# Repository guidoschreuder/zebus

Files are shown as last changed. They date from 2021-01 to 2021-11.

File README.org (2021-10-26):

#+TITLE:     Zebus
#+AUTHOR:    Guido Schreuder
#+EMAIL:     guido.schreuder@ruimtepuin.be

* Manage the Valliant heater

** Goals
Create system to control the heater

Conceived features:
- room controller:
  - display to represent status
    - requested room temperature
    - room temperature
    - heater flow temp (ebusd message 'FlowTemp', also rounded in `status01`)
    - heater return temp (ebusd message 'ReturnTemp', also rounded in `status01`)
    - outside temperature
    - heater mode: heating/hot water (ebusd message 'HwcDemand' or 'HwcWaterflow')
    - tap water temperature (ebusd message 'FlowTemp' when tap is running)
    - flame on/off (ebusd message 'Flame')
    - pump on/off (ebusd message 'WP')
    - heater modulation
    - power usage (?) to be tested (ebusd message 'PowerValue')
  - sensor for actual room temperature
  - controls to set required temperature
- +communicate date and outside temperature to heater unit+ impossible and irrelevant, see [[* +Broadcast datetime+]]
- control remotely using a telegram bot, that way we do not need to open any ports to the outside
- (LOW PRIO, MAYBE LATER) display graphs over time of relevant values

** Topology (work in progress)
- room controller (ESP32 + display + temp-sensor)
- retrieve outside temp from free API service like OpenWeatherMap +outdoor unit, communicates temperature to "master" ESP32 on heater unit over ESP-NOW+
- (LOW PRIO, MAYBE LATER) master forwards to MQTT for monitoring/graphing

** Challenges
- ✓ eBUS communication protocol (pretty much got this down)
- Valliant's eBUS commands are proprietary
- ESP32 ULP programming is in assembler

* tasks
Tasks should re-ordered so the first items should be the first things to pick up, items that are DONE need to move to [[* project log]]

** TODO determine preferred topology to use  (work in progress)
+consider ESP-NOW so "sensor" modules can profit from reduced "ON" time.+

+This needs a "master" though to forward to MQTT if required.+

+Good read and entry point is here: https://hackaday.io/project/174898-esp-now-weather-station+

New idea on topology is to use a single ESP32 as thermostat which harvests energy from eBUS for power.

The advantage is that there is no wireless communication needed for basic thermostat functionality.

This does however require a more sophisticated power design as we need a LiPo battery (or similar) with circuitry and most likely use of ESP32 ULP to stay within the power budget.

Wireless connectivity is still possible for things like getting NTP, outside temperature from a free API service and communicating as a telegram bot, but display and wireless need to repect the available energy budget.
** TODO prototype switching display on and off with mosfet
When operating in power-harvest mode we do not want the display on when maintenance chores are done.

The display does not have a pin to regulate the backlight, so it needs to be switched off completely when in sleep mode.
** TODO integrate a rotary encoder and buttons (capacitive?) for controlling the controller
** TODO integrate room temperature sensor
** TODO [#B] prototype power harvesting
Starting point are project that use solar energy like here https://randomnerdtutorials.com/power-esp32-esp8266-solar-panels-battery-level-monitoring/

This will include staring to use ESP32 ULP programming in assembler to measure the voltage/battery level in low power mode
** TODO [#C] create PCB with all components integrated
All basic functionality needs to be prototyped and tested before doing this.

Consider using JLCPCB assembly, this way we can use SMD without the hassle of sourcing SMD components, let alone soldering them
** TODO [#C] create case for thermostat unit

* documentation
** calculating power usage

#+NAME: ebusd raw log for getting data
#+BEGIN_SRC sh
2021-10-26 07:24:00.949 [update notice] sent read bai PartloadHcKW QQ=31: 20
2021-10-26 07:24:00.951 [bus notice] >3108b509030d0704ee<0001148f>00
2021-10-26 07:27:48.647 [update notice] sent read bai ModulationTempDesired QQ=31: 35.0
2021-10-26 07:27:48.650 [bus notice] >3108b509030d2e000c<00025e01a2>00
#+END_SRC

#+NAME: calculate current power for heating
#+BEGIN_SRC C
CurrentPower = PartloadHcKW * ModulationTempDesired / 100%

CurrentPower = 20 * 35.0 /100 = 7KW
#+END_SRC

discussion on calculating power consumption: https://github.com/john30/ebusd-configuration/issues/89

** code coverage
After running tests, code coverage report can be generated by executing the following commands:

#+NAME: code coverage generation
#+BEGIN_SRC sh
$ lcov --capture --directory .pio/build --output-file coverage.info
$ genhtml coverage.info --output-directory out
#+END_SRC

** display

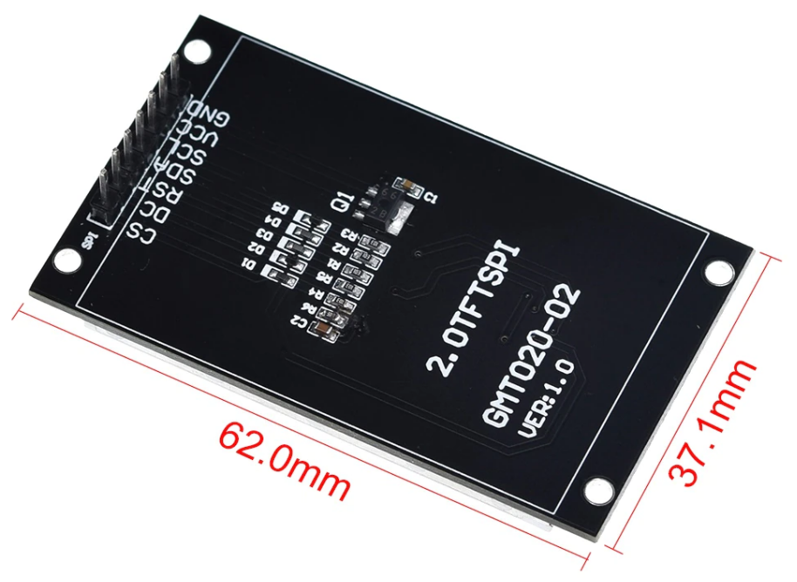
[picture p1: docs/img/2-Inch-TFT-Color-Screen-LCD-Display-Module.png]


driver IC: ST7789VW

size: 240x320 px

library used: TFT\under{}eSPI

bought here: https://www.aliexpress.com/item/4000830895622.html

| pinout | meaning          | ESP32   | note       |
|--------+------------------+---------+------------|
| CS     | chip select      | GND     | active low |
| DC     | SPI Data Command | GPIO 27 |            |
| RST    | Reset            | GPIO 5  |            |
| SDA    | SPI MOSI         | GPIO 23 |            |
| SCL    | SPI clock        | GPIO 18 |            |
| VCC    |                  | +3.3    |            |
| GND    |                  | GND     |            |

** random assortment of links
 - http://www.pittnerovi.com/jiri/hobby/electronics/ebus/index.html
 - https://github.com/slavikb/BaiMon/blob/master/BaiMon.ino
 - https://www.14core.com/wiring-and-flashing-programming-esp-32-esp32s-with-usb-ttl-uart/
 - https://www.thingforward.io/techblog/2017-08-08-embedded-testing-with-platformio-part-2.html
 - set datetime: https://github.com/john30/ebusd/issues/286
 - formatting C time struct: https://www.ibm.com/docs/en/i/7.3?topic=functions-strftime-convert-datetime-string

* project log
** DONE create hardware interface for eBUS
    CLOSED: [2021-01-17 Sun 01:48]
** DONE get hardware interface to work with ebusd and experiment a bit
    CLOSED: [2021-01-17 Sun 01:48]
** DONE build bus power supply so testing can be done in stand-alone mode
    CLOSED: [2021-01-17 Sun 01:50]
** DONE experiment with programming new ESP32 boards
    CLOSED: [2021-01-18 Mon 03:19]
that was easy as pie :)
** DONE get ESP32 to listen in on eBUS messages and forward them ad-verbum to serial port for monitoring/debugging
    CLOSED: [2021-01-24 Sun 05:14]
** DONE implement queues for actions "to be done" and "messages completed"
   CLOSED: [2021-08-30 Mon 00:29]
status:

implemented a pretty simple queue

later i found out about the provided facilities of FreeRTOS (live and learn...)

the simple mock queue is however still very usefull for unit-testing in native mode

actual implementation will use FreeRTOS queues provided by ESP-IDF/FreeRTOS
** DONE learn how to use FreeRTOS queues
     CLOSED: [2021-01-24 Sun 05:13]
** DONE use queues for storing historic message
     CLOSED: [2021-01-24 Sun 05:15]

** DONE reply to "Identification (Service 07h 04h)"
    CLOSED: [2021-01-24 Sun 04:28]

** DONE tackle the arbitration challenge
   CLOSED: [2021-08-30 Mon 00:29]
** DONE get ESP board to interface with 2.0" display
   CLOSED: [2021-08-29 Sun 19:06]
** DONE setup polls for basic data and extract the relevant data from the responses
   CLOSED: [2021-09-04 Sat 00:55]
suggested for this todo are some of the messages already known:
- FlowTemp
- ReturnTemp
- HwcWaterflow
- Flame

As a reward these values can already be put on display, gaining some instant gratification and bragging rights.

** DONE connect to WiFi
   CLOSED: [2021-09-05 Sun 19:55]
** DONE Setup and display time over NTP
   CLOSED: [2021-09-05 Sun 22:01]
** DONE display eBUS connectivity
   CLOSED: [2021-09-06 Mon 01:29]
** DONE figure out what our power budget is
   CLOSED: [2021-09-06 Mon 17:58]
   Shorting 390 Ohm across the eBUS still held an upper voltage of 20.2V and bus seemed to work fine.

   This equals a current draw of ~52mA, or 1.06W, this is actually quite substantial, this was measured with a really tiny copper wire (telephone wire) connection to the heater, so losses will be less on thicker wiring.

   Using 220 Ohm the bus still managed to do some communication but errors did occur, the maximum voltage dropped to 19.2V. This equals a current draw of ~87mA and a power of 1.68W! The resistor got really toasty and discoloured!

   At 336 Ohm (60mA, 1.2W) bus still behaved perfectly.

   In conclusion, round about 50mA or a little more seems to be a very safe limit with only a single device on the bus besides the heater.
** +Broadcast datetime+
+Send broadcast of datetime and check ebusd messages 'DCFState', 'DCFTimeDate', 'DateTime'.+

My line of thinking was completely wrong, i assumed the DCF77 device was "Yet Another eBUS device". It is not. It is a module connected to a separate port on the heater. The broadcasts (presumably) are by the heater when it has detected a DCF signal.

Further more, i have not found any way to set the date/time on the heater through eBUS, and believe me, i've tried.

In the end it is not really relevant anyway, the room controller takes on the full role of director anyway when controlling the heater over eBUS, so the date/time on the heater is then completely irrelevant.
** +send current room temperature to heater+
Irrelevant for the same reason outlined in [[* +Broadcast datetime+]], in eBUS mode the heater is just a rather dumb slave dancing to the tune of puppet master room controller

** DONE setup separerate ESP32 as temperature logger
   CLOSED: [2021-09-14 Tue 08:00]
read sensor and output value to serial port
** DONE setup ESP-NOW and communicate temperature sensor readings to room controller
   CLOSED: [2021-09-14 Tue 19:16]
** DONE switch ESP-NOW polling from master to slave
   CLOSED: [2021-09-20 Mon 03:08]
It makes little sense for the master to loose WiFi connection to send beacons because of channel switching. Instead the slave(s) should do this as they have no active WiFi connection to begin with.
** DONE implement HMAC on ESP-NOW messages
   CLOSED: [2021-09-22 Wed 00:22]
Data sent over ESP-NOW is not sensitive so encryption is not very relevant. However, we do not want rogue data being operated on by the controller.

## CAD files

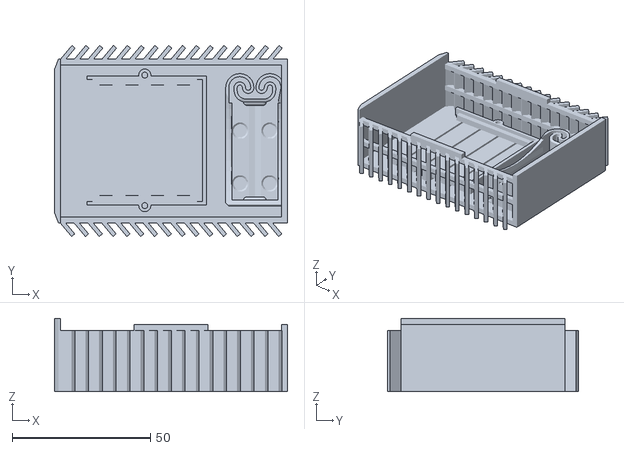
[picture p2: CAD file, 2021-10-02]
3d/outdoor-sensor/outdoor-sensor.stl
84.4 x 69.2 x 26.6

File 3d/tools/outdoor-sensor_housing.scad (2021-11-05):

// Which part would you like to see?
part = "box"; // [box:box only,front:front only]

// Heigth of box in mm (Inside).
height = 75; 

// Width of box in mm (Inside).
width = 52;

// Depth of box in mm (Inside).
depth = 16;

// Wall thicknes of box in mm.
thickness = 1.5; 

// Diameter of screw hole in mm.
diameter_hole = 0;

// Length of the slats in mm.
length_slats = 7;

// Pointed or flat roof?
roof = "flat"; // [pointed:pointed roof, flat:flat roof]

roof_angle = 115;

module housing(){
    cube([height,width+2*thickness,thickness]);
    rotate([0,-90,0])
        translate([0,0,-height-thickness])
            cube([depth+2*thickness,width+2*thickness,thickness]);
    if (roof == "flat") {
        rotate([0,0,90])
            cube([width+2*thickness,thickness,depth+3*thickness]);
    } else {
        rotate([0,0,90])
            cube([width+2*thickness,width,depth+3*thickness]);
    }
    for (a=[-1:5:height-5])
        translate([a,width+thickness+1,0])
            rotate([90,0,50])
                cube([length_slats,depth+thickness,1.5]);
    for (b=[0:5:height-5])
        translate([b,thickness,0])
            rotate([90,0,-50])
                cube([length_slats,depth+thickness,1.5]);
    translate([0,0,depth])
        cube([height,thickness,thickness]);
    translate([0,width+thickness,depth])
        cube([height,thickness,thickness]);
    translate([0,0,depth/2])
        cube([height,thickness,thickness]);
    translate([0,width+thickness,depth/2])
        cube([height,thickness,thickness]);
    translate([height/3,0,depth+thickness])
        cube([height/3,thickness,thickness]);
    translate([height/3,width+thickness,depth+thickness])
        cube([height/3,thickness,thickness]);
}

module cutouthousing(){
    translate([height/5,width/2+thickness,-1])
        cylinder(h=thickness+2, r=diameter_hole/2);

    translate([0,-2,depth+5*thickness])
        rotate([270,0,roof_angle])
            cube([width+thickness,depth+6*thickness,100]);
    translate([0,width+2*thickness+2,-thickness])
        rotate([90,0,-roof_angle])
            cube([width+4*thickness,depth+6*thickness,100]);   
}

module front(){
    cube([height,width+2*thickness,thickness]);    
}

module cutoutfront(){
    translate([height/3,0,0])
        cube([height/3,thickness,thickness]);
    translate([height/3,width+thickness,0])
        cube([height/3,thickness,thickness]);
}
    

$fn=50;

module box(){
    difference(){
        housing();
        cutouthousing();
    }
}

module door(){
    difference(){
        front();
        cutoutfront();
    }
}

print_part();

module print_part() {
	if (part == "box") {
		translate([-height/2-thickness,-width/2-thickness,0]) box();
	} else if (part == "front") {
		translate([-height/2,-width/2,0]) door();
	} 
}

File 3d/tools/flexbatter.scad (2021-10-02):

//////////////////////////////////////////////////////////////////////////////////////
///
///  FLEXBATTER: Flexing battery holder with built-in spring
///
///  This file generates battery holders for arbitrary cylindrical sizes.
///  The number of batteries compartments, the number of batteries in each compartment
///  and the battery size are fully parametrized.
///
///  The usual metallic spring at the minus pole is replaced by a
///  flexible printed spring, which is pressing the contacts firmly to 
///  the battery.
///
///  The contacts for the plus and minus pole can easily be made by
///  a few windings of the uninsulated ends of the connecting wires.
///  Each battery compartment contains are several holes to the outside
///  as well ad to the neighboring compartments, through which connecting
///  wires can be passed for easy configuring of parallel, serial or
///  balanced-serial battery packs.
///  
///  The preconfigured battery sizes are:
///  AA, AAA, C, D, 18650(Li-Ion), 18650P(protected Li-Ion), CR123A(16340)
///  
///  Given that the printed plastic spring needs to be flexible, ABS is the material
///  of choice here.
///
//////////////////////////////////////////////////////////////////////////////////////
///
///  2014-09-09 Heinz Spiess, Switzerland
///  2015-07-25 multi-cell compartments added
///
///  released under Creative Commons - Attribution - Share Alike licence (CC BY-SA)
//////////////////////////////////////////////////////////////////////////////////////

// build a cube with chamfered edges
module chamfered_cube(size,d=1){
   hull(){
     translate([d,d,0])cube(size-2*[d,d,0]);
     translate([0,d,d])cube(size-2*[0,d,d]);
     translate([d,0,d])cube(size-2*[d,0,d]);
   }
}


// draw an arc width height h between radius r1..r2 and angles a1..a2
module arc(r1,r2,h,a1=0,a2=0){
     if(a2-a1<=180){
        difference(){
           cylinder(r=r2,h=h);
           translate([0,0,-1])cylinder(r=r1,h=h+2);
	   rotate(a2)translate([-r1-r2,0,-1])cube([2*(r1+r2),2*(r1+r2),h+2]);
	   rotate(a1+180)translate([-r1-r2,0,-1])cube([2*(r1+r2),2*(r1+r2),h+2]);
        }
     } else {
           difference(){
              cylinder(r=r2,h=h);
              translate([0,0,-1])cylinder(r=r1,h=h+2);
              intersection(){
	       rotate(a2)translate([-r1-r2,0,-1])cube([2*(r1+r2),2*(r1+r2),h+2]);
	       rotate(a1+180)translate([-r1-r2,0,-1])cube([2*(r1+r2),2*(r1+r2),h+2]);
	      }
           }
     }
}

/////////////////////////////////////////////////////////////////////////////////
// sline - generate a "snake line" of width w and height h 
// with a arbitrary sequence of segments defined by a radius and a turning angle
//
//   angle[i] > 0  left turn / counter-clockwise
//   angle[i] < 0  left turn / clockwise
//   angle[i] = 0  straight segment with length radius[i]
//
/////////////////////////////////////////////////////////////////////////////////
// Heinz Spiess, 2014-09-06 (CC BY-SA)
/////////////////////////////////////////////////////////////////////////////////
module sline(angle,radius,i,w,h){
   r=abs(radius[i]);
   a=angle[i];
   scale([angle[i]>=0?1:-1,1,1])
         translate([a?r:0,0,0]){
	    translate([-w/2,-r-0.01,0])cube([w,0.02,h]); // tiny overlap!
            if(a)arc(r-w/2,r+w/2,h,a);
	    else if(r>0)translate([-w/2,-r,0])cube([w,r,h]);
      if(i+1<len(angle))
           rotate(angle[i])
	      translate([a?-r:0,a?0:-r,0])
	         sline(angle,radius,i+1,w,h);
  }
}

ew=0.56;   // extrusion width
eh=0.25;   // extrusion height

//////////////////////////////////////////////////////////////////////////////////
//
//  FLEXBATTER:  Flexing battery holder with integrated plastic spring
//
//////////////////////////////////////////////////////////////////////////////////
module flexbatter(
  n=1,             // number of compartments side by side
  m=1,             // number of cells in one compartment
  l=65,            // length of cell
  d=18,            // diameter of cell
  hf=0.75,         // relative hight of cell (1=full diameter)
  shd=3,           // screw hole diameter
  eps=0.28,        // extra diameter space 
  oh=0,            // overhang to avoid lifting of cell
  el=0,            // extra spring length (needed for small cells)
  xchan=[1/4,3/4], // relative position of traversal wire channels
  deepen=0,        // relative deepening for side grip of batteries 
  df=1,            // relative deepening radius
  lcorr=0,         // length correction for multicell compartments
  $fn=24
  ){

  w = (m>1?6:4)*ew;  // case wall thickness
  wz = 2;            // bottom wall thickness
  ws = 2*ew; // spring wall thickness
  ch = ws; // edge chamfering

  r = d/5+2*ws; // linear spring length (depends on sline() call!)
  L = m*l+lcorr;// corrected overall lenth
  lc = L/m;     // corrected cell length

   for(i=[0:n-1])translate([0,i*(d+2*w-ws),0]){ // generate n battery cases
      difference(){
         
         union(){
            difference(){
               // main body
               translate([0,-w-d/2,0])
	          chamfered_cube([L+w,d+2*w+(i<n-1?ws:0),hf*d+wz+ch],ch);
	       // main cavity
               jmin=deepen>0?0:-1;
	       for(j=[0:m-1])translate([j*lc,0,0])hull(){
                  translate([-0.01,-d/2+(j>jmin?oh:0),wz])cube([lc/4,d-(j>jmin?2*oh:0),d+1]);
                  translate([lc*0.75,-d/2+(j<m-1?oh:0),wz])cube([lc/4+0.01,d-(j<m-1?2*oh:0),d+1]);
               }
	       // cavity for locating plastic spring
               translate([-1,-d/2,-1])cube([2,d,d+wz+2]);
	       // small cylindrical carving of walls and bottom
	       translate([-1,0,d/2+wz])rotate([0,90,0])cylinder(r=d/2+eps,h=L+1);
            }
      
            // plastic spring for minus pole
            for(sy=[-1,1])scale([1,sy,1]) {
               D=d+2*w-2*ws-0.7;
               translate([ch,d/2+w-ws/2,0])rotate(-90)
		  //sline([90,0,120,90,120,90,0],[d/8+2,d/6,d/8-1,d/8,-d/8,d/8,d/2],0,ws,hf*d+w);
		  sline([0,180,0,180,0,-180,0,90,0],[r+ch+el,D/4,el,D/12,el/2,D/12,1+el/2,D/5,D/3],0,ws,hf*d+wz);


            }
         }
      
         // lower and upper holes for contacts
         for(z=[-2*ws,2*ws])
            translate([-2*ws,-w,wz-ws/2+d/2+z])cube([L+2*w+2,2*w,ws]);
      
         // longitudinal bottom wire channel
         translate([-2*ws,0,0])rotate([0,90,0])cylinder(r=wz/2,h=L+w+2+r,$fn=5);
      
         // traversal bottom wire channels
         for(x=L*xchan)translate([x,-d/2-w-1,-eh]) rotate([-90,0,0])cylinder(r=wz/2,h=d+2*w+ws+2,$fn=6);
   
         // grip deepening
	 if(deepen!=0)
	    for (j=[(deepen>0?0:m-1):m-1])
            translate([j*lc+lc/2-0.5,-d/2-w-0.01,wz+d+df*l])
	       rotate([-90,0,0]){
              adeepen=deepen>0?deepen:-deepen;
	          cylinder(r=df*l+adeepen*d,h=d+2*w+2*ws+2,$fn=72);
	          if(i==0)cylinder(r1=df*l+adeepen*d+ch,r2=df*l+adeepen*d,h=ch+0.02,$fn=72);
	          if(i==n-1)translate([0,0,d+2*w-ch])cylinder(r2=df*l+adeepen*d+ch,r1=df*l+adeepen*d,h=ch+0.02,$fn=72);

               }
         // conical screw holes in corners
         for(x=[7+shd,L-2*shd])for(y=[-d/2+shd,d/2-shd])
             translate([x,y,-1]){
                cylinder(r=shd/2,h=wz+2);
                translate([0,0,wz-shd/2+1])cylinder(r1=shd/2,r2=shd,h=shd/2+0.01);
             }

         // holes for wires passing inside
         for(sy=[-1,1])scale([1,sy,1]){
	    translate([L-1,-d/2,wz])cube([w+2,2,2]);
            for(x=[3,L-7])translate([x,-d/2-w-ws-1,wz])cube([3,w+ws+3,2]); 
            translate([3,-d/2+w/2-0.75,-1])cube([3,1.5,wz+2]); 
            translate([-0.5,-d/2+w/2,0])rotate([0,90,0])cylinder(r=w/2,h=6.5,$fn=5);
         }

         // engrave battery symbol
	 for(j=[0:m-1])translate([j*lc,0,0]){
	    translate([w+l/2,d/4+1,wz])cube([l/5,d/4.5,4*eh],true);
	    translate([w+l/2+l/10,d/4+1,wz])cube([d/7,d/10,4*eh],true);
	    // engrave plus symbol
	    sy=(l>12*shd)?1:-1; // for short batteries +- on the side
	       translate([w+l/2+l/(sy>0?5:10),sy*(d/4+1),wz]){
	          cube([1,d/4,4*eh],true);
	          cube([d/4,1,4*eh],true);
               }
	    // engrave minus symbol
	       translate([w+l/2-l/(sy>0?5:10),sy*(d/4+1),wz])
	          cube([1,d/4,4*eh],true);
            
	 }
   
         //correction for middle separators
         //if(i<n-1) translate([-d,d/2+w-ws/2,-1])cube([d,ws/2+0.1,d+2]);
	 //else translate([1,d/2+w,-0.01])cylinder(r1=ch,r2=0,h=ch);
         //if(i>0) translate([-d,-d/2-w-0.1,-1])cube([d,ws/2+0.1,d+2]);
	 //else translate([1,-d/2-w,-0.01])cylinder(r1=ch,r2=0,h=ch);


      }


      // horizontal contact bulges (+ and - pole)
      for(x=[-0.3,L])
         hull()for(y=[-3+el,3-el])
            translate([x,y,wz+d/2])sphere(r=ws);
   
      // vertical contact bulge (+ pole only)
      if(0)hull()for(z=[-3+el,3-el])for(x=[0,w-ws])
            translate([L+x,0,wz+d/2+z])sphere(r=ws);



   }

}
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

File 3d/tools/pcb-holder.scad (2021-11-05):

// Width of the PCB
pcb_width = 50.1;

// Length of the PCB
pcb_length = 50.1;

// PCB thickness
pcb_thickness = 1.6;

// Height from top of baseplate to bottom of PCB
pcb_heigth_offset = 3.5;

// Thickness of base plate
baseplate_thickness = 1.5;

// Thickness of the ledge that supports the PCB
pcb_support_width = 2.1;

pcb_support_clear_corner = 2.1;

// Thickness of the ridge that keeps the PCB
ridge_width = 3.7;

// number of slats cut out of baseplate
num_slats = 6;

sides = "none"; // ["none", "front", "back", "both"]

// number of PCB retainment screws per side
num_pcb_retainment_screws_per_side = 1;

// diameter of the PCB retainment screw hole
pcb_retainment_screws_hole_diameter = 3.2;

print_part();

num_sides = (sides == "both") ? 2 : ((sides == "front" || sides == "back") ? 1 : 0);
total_width = pcb_width + 2 * ridge_width;
total_length = pcb_length + num_sides * ridge_width;
retainment_screw_x_offset = .3 * pcb_retainment_screws_hole_diameter;

module screw_body(x, y, diameter, cutout=false) {
    h = baseplate_thickness + pcb_heigth_offset + pcb_thickness;
    dim = cutout ? diameter / 2 : diameter;
    translate([x, y, 0]) 
        cylinder(h,  dim, dim, $fs=.5);
}

module retainment_screws(cutout=false) {
  screw_inc = pcb_length / num_pcb_retainment_screws_per_side;
  x_offset = pcb_retainment_screws_hole_diameter - retainment_screw_x_offset;
  for (i = [1:num_pcb_retainment_screws_per_side]) {
    y = num_pcb_retainment_screws_per_side == 1 ? pcb_length / 2 : (i - .5) * screw_inc;
    screw_body(ridge_width - x_offset, y, pcb_retainment_screws_hole_diameter, cutout);
    screw_body(pcb_width + ridge_width + x_offset, y, pcb_retainment_screws_hole_diameter, cutout);
    }
}

module holder_base() {
    
    // baseplate
    cube([total_width, pcb_length, baseplate_thickness]);
    
    // draw left support
    translate([ridge_width, pcb_support_clear_corner, baseplate_thickness]) 
        cube([pcb_support_width, pcb_length - 2 * pcb_support_clear_corner, pcb_heigth_offset]);
    // draw left ridge
    translate([0, 0, baseplate_thickness]) 
        cube([ridge_width, pcb_length, pcb_heigth_offset + pcb_thickness]);

    // draw right support
    translate([pcb_width - pcb_support_width + ridge_width, pcb_support_clear_corner, baseplate_thickness]) 
      cube([pcb_support_width + ridge_width, pcb_length - 2 * pcb_support_clear_corner, pcb_heigth_offset]);
    // draw right ridge
    translate([pcb_width + ridge_width, 0, baseplate_thickness]) 
      cube([ridge_width, pcb_length, pcb_heigth_offset + pcb_thickness]);
    
    // draw sides
    if (sides == "front" || sides == "both") {
        translate([0, -ridge_width, 0]) 
            cube([total_width, ridge_width, baseplate_thickness + pcb_heigth_offset + pcb_thickness]);
    }
    if (sides == "back" || sides == "both") {
        translate([0, pcb_length, 0]) 
            cube([total_width, ridge_width, baseplate_thickness + pcb_heigth_offset + pcb_thickness]);
    }

}

module holder_slats_cutout() {
    if(num_slats > 0) {
        slat_inc = pcb_length / (2 * num_slats + 1);
        echo(slat_inc=slat_inc);
        for (i = [1:num_slats]) {
            y = (2 * (i - 1) + 1) * slat_inc;
            translate([0, y, 0])
                cube([pcb_width + 2 * pcb_support_width + 2 * ridge_width, slat_inc, baseplate_thickness]);
        }
    }
}

module pcb_cutout() {
    translate([ridge_width, 0, baseplate_thickness + pcb_heigth_offset]) 
        cube([pcb_width, pcb_length, pcb_thickness]);
}

module holder() {    
    difference() {
        union() {
            difference(){
              holder_base();
              holder_slats_cutout();
            }
          retainment_screws();
        }
        retainment_screws(true);
        pcb_cutout();
    }
}

module print_part() {
    translate([-total_width/2, -total_length /2, 0]) holder();
}

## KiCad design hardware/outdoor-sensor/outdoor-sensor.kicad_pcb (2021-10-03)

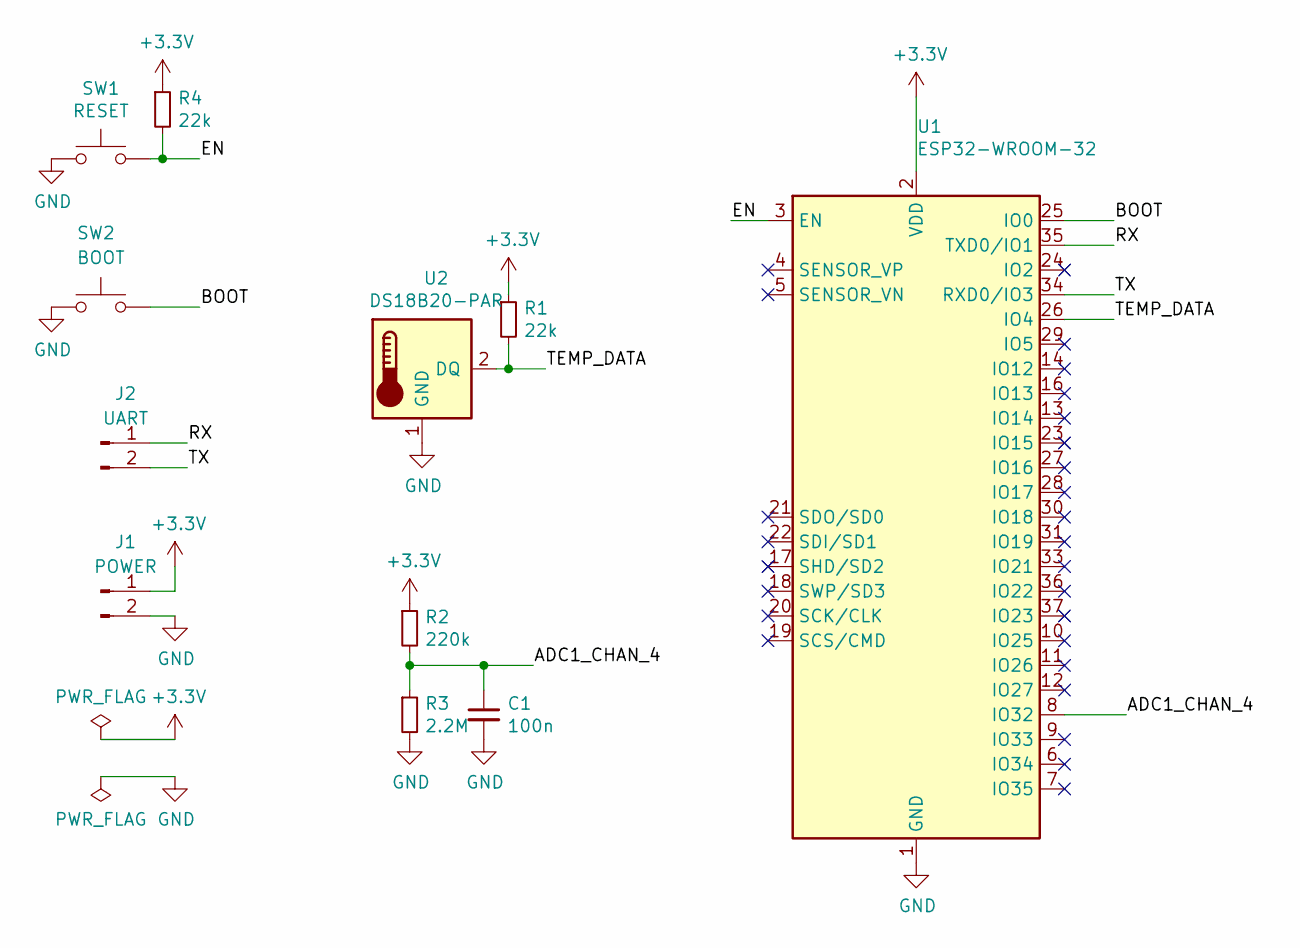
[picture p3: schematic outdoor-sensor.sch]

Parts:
C1: 100n; C_Disc_D6.0mm_W2.5mm_P5.00mm
J1: POWER; PinHeader_1x02_P2.54mm_Vertical
J2: UART; PinHeader_1x02_P2.54mm_Vertical
R1, R4: 22k; R_Axial_DIN0207_L6.3mm_D2.5mm_P7.62mm_Horizontal
R2: 220k; R_Axial_DIN0207_L6.3mm_D2.5mm_P7.62mm_Horizontal
R3: 2.2M; R_Axial_DIN0207_L6.3mm_D2.5mm_P7.62mm_Horizontal
SW1: RESET; SW_SPST_B3S-1000
SW2: BOOT; SW_SPST_B3S-1000
U1: ESP32-WROOM-32
U2: DS18B20-PAR; TO-92_Inline

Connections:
+3V3: J1.1, R1.1, R2.1, R4.1, U1.2 (VDD)
/ADC1_CHAN_4: C1.1, R2.2, R3.1, U1.8 (IO32)
/BOOT: SW2.2, U1.25 (IO0)
/EN: R4.2, SW1.2, U1.3 (EN)
/RX: J2.1, U1.35 (TXD0/IO1)
/TEMP_DATA: R1.2, U1.26 (IO4), U2.2 (DQ)
/TX: J2.2, U1.34 (RXD0/IO3)
GND: C1.2, J1.2, R3.2, SW1.1, SW2.1, U1.1 (GND), U1.15 (GND), U1.38 (GND), U1.39 (GND), U2.1 (GND)

Board: 2 copper layers, 11 parts (0 on the bottom side), 8 nets, no tracks yet.

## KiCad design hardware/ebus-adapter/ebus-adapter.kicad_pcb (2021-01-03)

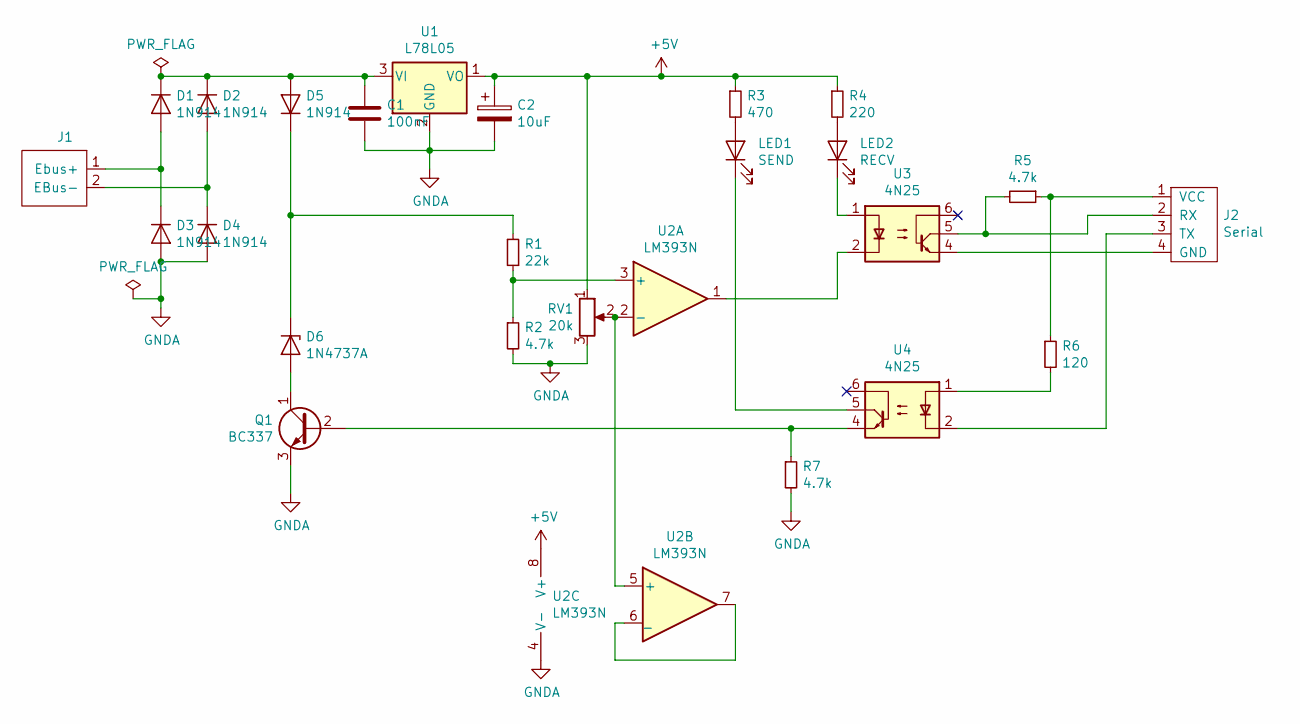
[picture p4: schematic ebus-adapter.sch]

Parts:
C1: 100nF; C_Disc_D5.0mm_W2.5mm_P5.00mm
C2: 10uF; CP_Radial_D5.0mm_P2.00mm
D1, D2, D3, D4, D5: 1N914; D_DO-35_SOD27_P7.62mm_Horizontal
D6: 1N4737A; D_DO-41_SOD81_P10.16mm_Horizontal
J1: EBus-Connector; TerminalBlock_bornier-2_P5.08mm
J2: Serial; PinHeader_1x04_P2.54mm_Vertical
LED1: SEND; LED_D3.0mm
LED2: RECV; LED_D3.0mm
Q1: BC337; TO-92_Inline
R1: 22k; R_Axial_DIN0207_L6.3mm_D2.5mm_P7.62mm_Horizontal
R2, R5, R7: 4.7k; R_Axial_DIN0207_L6.3mm_D2.5mm_P7.62mm_Horizontal
R3: 470; R_Axial_DIN0207_L6.3mm_D2.5mm_P7.62mm_Horizontal
R4: 220; R_Axial_DIN0207_L6.3mm_D2.5mm_P7.62mm_Horizontal
R6: 120; R_Axial_DIN0207_L6.3mm_D2.5mm_P7.62mm_Horizontal
RV1: 20k; Potentiometer_Bourns_3386F_Vertical
U1: L78L05; TO-92_Inline
U2: LM393N; DIP-8_W7.62mm
U3, U4: 4N25; DIP-6_W7.62mm

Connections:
+5V: C2.1, R3.1, R4.1, RV1.1, U1.1 (VO), U2.8 (V+)
GNDA: C1.2, C2.2, D3.2 (A), D4.2 (A), Q1.3 (E), R2.2, R7.2, RV1.3, U1.2 (GND), U2.4 (V-)
unnamed: C1.1, D1.1 (K), D2.1 (K), D5.2 (A), U1.3 (VI)
unnamed: D1.2 (A), D3.1 (K), J1.1 (Ebus+)
unnamed: D2.2 (A), D4.1 (K), J1.2 (EBus-)
unnamed: D5.1 (K), D6.1 (K), R1.1
unnamed: D6.2 (A), Q1.1 (C)
unnamed: J2.1 (VCC), R5.1, R6.1
unnamed: J2.2 (RX), R5.2, U3.5
unnamed: J2.3 (TX), U4.2
unnamed: J2.4 (GND), U3.4
unnamed: LED1.1 (K), U4.5
unnamed: LED1.2 (A), R3.2
unnamed: LED2.1 (K), U3.1
unnamed: LED2.2 (A), R4.2
unnamed: Q1.2 (B), R7.1, U4.4
unnamed: R1.2, R2.1, U2.3 (+)
unnamed: R6.2, U4.1
unnamed: RV1.2, U2.2 (-), U2.5 (+)
unnamed: U2.1, U3.2
unnamed: U2.6 (_), U2.7

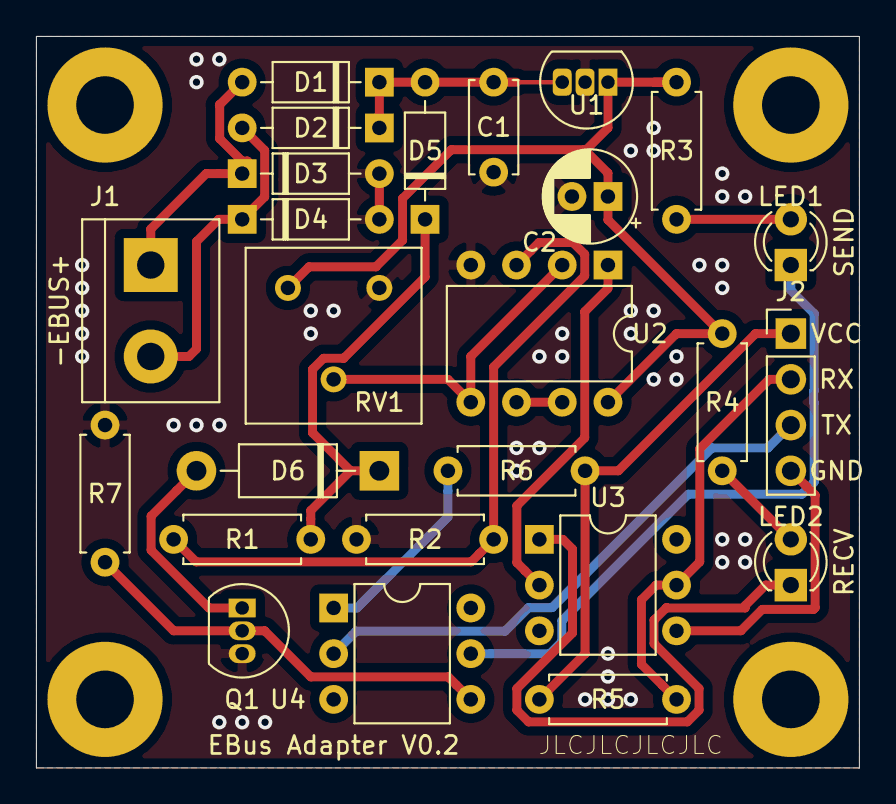
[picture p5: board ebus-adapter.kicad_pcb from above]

Board: 2 copper layers, 45.7 x 40.6 mm, 29 parts (0 on the bottom side), 21 nets.

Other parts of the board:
H1, H2, H3, H4: MountingHole_Pad; MountingHole_3.2mm_M3_Pad

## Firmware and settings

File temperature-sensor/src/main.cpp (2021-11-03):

#define LOG_LOCAL_LEVEL ESP_LOG_DEBUG

#include <DallasTemperature.h>
#include <OneWire.h>
#include <driver/adc.h>

#include "tcpip_adapter.h"
#include "esp_log.h"
#include "esp_now.h"
#include "nvs_flash.h"
#include "esp_wifi.h"
#include "espnow-config.h"
#include "espnow-hmac.h"
#include "espnow-types.h"

#define TAG "temperature-sensor"

#define ONE_WIRE_PIN 4
#define SCAN_MASTER_INTERVAL_MILLIS 1000
#define MAX_SEND_ATTEMPT 3

#define ADC_SAMPLES 16

#define mS_TO_uS(millis) (millis * 1000)

OneWire oneWire(ONE_WIRE_PIN);
DallasTemperature sensors(&oneWire);

#define INVALID_CHANNEL -1
RTC_DATA_ATTR bool master_found = false;
RTC_DATA_ATTR int8_t master_channel = INVALID_CHANNEL;
RTC_DATA_ATTR uint8_t master_mac_addr[6] = {0};
RTC_DATA_ATTR uint64_t interval_millis = SCAN_MASTER_INTERVAL_MILLIS;

uint8_t sendAttempt = 0;
bool sendGotResult = false;
bool sendSuccess = false;

// declarations
void wifi_init();
void espnow_init();
void onEspNowDataRecv(const uint8_t * mac_addr, const uint8_t *incomingData, int len);
void onEspNowDataSent(const uint8_t *mac_addr, esp_now_send_status_t status);
bool findMaster();
esp_err_t doSendData(espnow_msg_temperature_sensor data);
void sendData(espnow_msg_temperature_sensor data);
float getTemperature();
float getSupplyVoltage();

// implementations, public
extern "C" {
void app_main();
}

void app_main() {
  Serial.begin(115200);

  nvs_flash_init();

  wifi_init();

  // setup ESP-NOW
  espnow_init();

  // setup temperature sensor
  sensors.begin();
  sensors.setResolution(9);

  // setup ADC
  adc1_config_width(ADC_WIDTH_BIT_12);
  adc1_config_channel_atten(ADC1_CHANNEL_4, ADC_ATTEN_11db);

  if (findMaster()) {
    espnow_msg_temperature_sensor data;
    data.base.type = espnow_temperature_sensor_data;
    strcpy(data.location, SENSOR_LOCATION);
    data.temperatureC = getTemperature();
    data.supplyVoltage = getSupplyVoltage();
    sendData(data);
  } else {
    ESP_LOGW(TAG, "Master not found");
  }

  ESP_LOGD(TAG, "Uptime: %ld", millis());
  ESP_LOGD(TAG, "Going to deep sleep");

  esp_sleep_pd_config(ESP_PD_DOMAIN_RTC_PERIPH, ESP_PD_OPTION_OFF);
  esp_sleep_enable_timer_wakeup(mS_TO_uS(interval_millis));
  esp_deep_sleep_start();
}

// implementations, local
void wifi_init() {
    tcpip_adapter_init();
    ESP_ERROR_CHECK(esp_event_loop_create_default());
    wifi_init_config_t cfg = WIFI_INIT_CONFIG_DEFAULT();
    ESP_ERROR_CHECK( esp_wifi_init(&cfg) );
    ESP_ERROR_CHECK( esp_wifi_set_storage(WIFI_STORAGE_RAM) );
    ESP_ERROR_CHECK( esp_wifi_set_mode(WIFI_MODE_STA) );
    ESP_ERROR_CHECK( esp_wifi_start());

#if CONFIG_ESPNOW_ENABLE_LONG_RANGE
    ESP_ERROR_CHECK( esp_wifi_set_protocol(ESPNOW_WIFI_IF, WIFI_PROTOCOL_11B|WIFI_PROTOCOL_11G|WIFI_PROTOCOL_11N|WIFI_PROTOCOL_LR) );
#endif
}

void espnow_init() {
  ESP_ERROR_CHECK(esp_now_init());
  ESP_ERROR_CHECK(esp_now_register_send_cb(onEspNowDataSent));
  ESP_ERROR_CHECK(esp_now_register_recv_cb(onEspNowDataRecv));

  static esp_now_peer_info_t peerInfo;
  memcpy(peerInfo.peer_addr, espnow_broadcast_address, sizeof(espnow_broadcast_address));
  peerInfo.channel = 0;
  peerInfo.encrypt = false;

  ESP_ERROR_CHECK(esp_now_add_peer(&peerInfo));
}

void onEspNowDataRecv(const uint8_t * mac_addr, const uint8_t *incomingData, int len) {
  if (incomingData[0] == espnow_ping_reply) {
    espnow_msg_ping_reply ping_reply;
    if (!validate_and_copy(&ping_reply, sizeof(ping_reply), incomingData, len)) {
      ESP_LOGE(TAG, "%s", getLastHmacError());
      return;
    }

    master_channel = ping_reply.channel;
    interval_millis = ping_reply.expected_interval_millis;
    memcpy(&master_mac_addr, mac_addr, sizeof(master_mac_addr));
    master_found = true;
    ESP_LOGI(TAG, "Master found at channel: %d", master_channel);
 }
}

void onEspNowDataSent(const uint8_t *mac_addr, esp_now_send_status_t status) {
  sendGotResult = true;
  sendSuccess = (status == ESP_NOW_SEND_SUCCESS);

  if (!sendSuccess) {
    ESP_LOGW(TAG, "Packet failed to deliver at attempt %d of %d", sendAttempt, MAX_SEND_ATTEMPT);
  }
}

bool findMaster() {
  if (master_found) {
    return true;
  }

  wifi_country_t country;
  ESP_ERROR_CHECK(esp_wifi_get_country(&country));

  espnow_msg_ping ping;
  ping.base.type = espnow_ping;
  fillHmac((espnow_msg_base *) &ping, sizeof(ping));

  ESP_ERROR_CHECK(esp_wifi_set_promiscuous(true));
  for (uint8_t channel = country.schan; channel < country.schan + country.nchan  && !master_found; channel++) {
    ESP_ERROR_CHECK(esp_wifi_set_channel(channel, WIFI_SECOND_CHAN_NONE));

    esp_err_t result = esp_now_send(espnow_broadcast_address, (uint8_t *)&ping, sizeof(ping));
    if (result != ESP_OK) {
      ESP_LOGE(TAG, "There was an error sending ping on channel %d", channel);
      continue;
    }
    // wait for response
    for (int i = 0; !master_found && i < 10; i++) {
      vTaskDelay(pdMS_TO_TICKS(20));
    }
  }
  ESP_ERROR_CHECK(esp_wifi_set_promiscuous(false));

  return master_found;
}

esp_err_t doSendData(espnow_msg_temperature_sensor data) {
  if (!esp_now_is_peer_exist(master_mac_addr)) {

    // NOTE: needs to be declared `static` otherwise the follow error occurs:
    //   E (3263) ESPNOW: Peer interface is invalid
    //   ESP_ERROR_CHECK failed: esp_err_t 0x3066 (ESP_ERR_ESPNOW_ARG) at 0x40088970
    static esp_now_peer_info_t peerInfo;
    memcpy(peerInfo.peer_addr, master_mac_addr, sizeof(peerInfo.peer_addr));
    peerInfo.channel = 0;
    peerInfo.encrypt = false;
    ESP_ERROR_CHECK(esp_now_add_peer(&peerInfo));
  }

  ESP_ERROR_CHECK(esp_wifi_set_promiscuous(true));
  ESP_ERROR_CHECK(esp_wifi_set_channel(master_channel, WIFI_SECOND_CHAN_NONE));
  ESP_ERROR_CHECK(esp_wifi_set_promiscuous(false));

  fillHmac((espnow_msg_base *) &data, sizeof(data));

  return esp_now_send(master_mac_addr, (uint8_t *) &data, sizeof(data));
}

void sendData(espnow_msg_temperature_sensor data) {
  do {
    sendAttempt++;
    sendGotResult = false;

    if (sendAttempt > 1) {
      vTaskDelay(pdMS_TO_TICKS(200));
    }
    esp_err_t result = doSendData(data);
    if (result != ESP_OK) {
      ESP_LOGE(TAG, "Failed to send packet with reason '%s' at attempt %d of %d", esp_err_to_name(result), sendAttempt, MAX_SEND_ATTEMPT);
    } else {
      while(!sendGotResult) {
        vTaskDelay(pdMS_TO_TICKS(10));
      }
    }
  } while(!sendSuccess && sendAttempt < MAX_SEND_ATTEMPT);

  ESP_LOGD(TAG, "Send result %s after %d attempt(s)", sendSuccess ? "OK" : "FAIL", sendAttempt);
}

float getTemperature() {
  sensors.requestTemperatures();
  float temp = sensors.getTempCByIndex(0);
  ESP_LOGD(TAG, "Temperature: %f", temp);
  return temp;
}

float getSupplyVoltage() {
  int val = 0;
  for (int i = 0; i < ADC_SAMPLES; i++) {
    val += adc1_get_raw(ADC1_CHANNEL_4);
  }
  float result = (val * ADC_REF_VOLTAGE) / (ADC_REF_SAMPLE * ADC_SAMPLES);
  ESP_LOGD(TAG, "Voltage: sample: %d => %f", val / ADC_SAMPLES, result);
  return result;
}

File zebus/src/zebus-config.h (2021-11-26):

#ifndef ZEBUS_CONFIG_H
#define ZEBUS_CONFIG_H

// application configuration
#define ZEBUS_APPNAME "Zebus"

#define ZEBUS_LOG_LEVEL ESP_LOG_DEBUG

// Network configuration
#define ZEBUS_WIFI_CONFIG_AP_PASSWORD_LENGTH 8
#define ZEBUS_WIFI_HOSTNAME "zebus"

#define ZEBUS_NTP_SERVER "1.be.pool.ntp.org"
#define ZEBUS_NTP_GMT_OFFSET_SEC 3600
#define ZEBUS_NTP_GMT_DST_OFFSET_SEC 3600
#define ZEBUS_NTP_REFRESH_INTERVAL_MS (5 * 60 * 1000)

// MQTT config
#define ZEBUS_MQTT_HOST "nas.home.arpa"
#define ZEBUS_MQTT_TRANSPORT MQTT_TRANSPORT_OVER_TCP
#define ZEBUS_MQTT_UPDATE_INTERVAL_MS (2 * 1000)

// Sensors
#define ZEBUS_SENSOR_INTERVAL_MS 60 * 1000

// Display
#define ZEBUS_BACKLIGHT_PIN 13
#define ZEBUS_BACKLIGHT_FADEOUT_MS 5000

// eBUS configuration
#define ZEBUS_EBUS_TICK_MS 1000

#define EBUS_UART_NUM 1
#define EBUS_UART_RX_PIN 32
#define EBUS_UART_TX_PIN 33

#define EBUS_MASTER_ADDRESS 0x00
#define EBUS_TELEGRAM_HISTORY_QUEUE_SIZE 50
#define EBUS_TELEGRAM_SEND_QUEUE_SIZE 20
#define EBUS_TELEGRAM_RECEIVE_BYTE_QUEUE_SIZE 1024
#define EBUS_MAX_TRIES 2
#define EBUS_MAX_LOCK_COUNTER 4

#define EBUS_HEATER_MASTER_ADDRESS 0x03
#define EBUS_HEATER_MAX_FLOW 12.0

#define EBUS_DEVICE_VENDOR_ID 0xDD
#define EBUS_DEVICE_NAME ZEBUS_APPNAME
#define EBUS_DEVICE_SW_VERSION 0x0102
#define EBUS_DEVICE_HW_VERSION 0x0304

// Telegram configuration
#define ZEBUS_TELEGRAM_MTBS_MS 500

#endif

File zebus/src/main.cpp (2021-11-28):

#include "main.h"

#include "display/zebus-display.h"
#include "network/zebus-wifi.h"
#include "zebus-ebus.h"
#include "zebus-events.h"
#include "zebus-state.h"
#include "zebus-system-info.h"
#include "zebus-temp-control.h"

struct system_info_t* system_info = new system_info_t();

static EventGroupHandle_t zebus_state_event_group;

extern "C" {
void app_main();
}

void app_main() {
  ESP_LOGI(ZEBUS_LOG_TAG, "Setup %s", ZEBUS_APPNAME);

  zebus_state_event_group = xEventGroupCreate();

  initEventLoop();

  xTaskCreate(&displayTask, "displayTask", 2048, zebus_state_event_group, 5, NULL);
  xTaskCreate(&wiFiTask, "wiFiTask", 8192, zebus_state_event_group, 3, NULL);
  xTaskCreate(&ebusTask, "ebusTask", 2048, NULL, 5, NULL);
  xTaskCreate(&stateTask, "stateTask", 2048, zebus_state_event_group, 5, NULL);
  xTaskCreate(&temparatureControlTask, "temparatureControlTask", 2048, NULL, 4, NULL);
}

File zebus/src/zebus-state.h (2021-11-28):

#ifndef ZEBUS_STATE_H
#define ZEBUS_STATE_H

#include <freertos/FreeRTOS.h>
#include <freertos/event_groups.h>

#include "zebus-log.h"

enum state_bits {
  DISPLAY_ENABLED  = (1 << 0),
  DISPLAY_DISABLED = (1 << 1),
  WIFI_ENABLED     = (1 << 2),
  WIFI_DISABLED    = (1 << 3),
};

void stateTask(void *pvParameter);

#endif

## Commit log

2021-01-03 initial schematic and board version
    [ebus-adapter.kicad_pcb, ebus-adapter.sch]
2021-01-03 Corrected footprint of 7805 voltage ragulator
    [ebus-adapter.kicad_pcb, ebus-adapter.sch]
2021-01-09 rename folder
    [ebus-adapter.kicad_pcb, ebus-adapter.sch]
2021-01-10 Fix error when running 'pio run'
    [main.cpp]
2021-01-20 dev commit: experimenting with temperature logger to MQTT
2021-01-21 switchover framwework from Arduino to ESP-IDF
2021-01-22 properly switch to mock-queue for testing
2021-01-22 fixes after testing on device
    [main.cpp]
2021-01-22 modify ports after reprogramming CP2102 on device
2021-01-28 Abort on UART errors
    [main.cpp]
2021-08-29 Display working with 'arduino, espdif' as framework
2021-09-01 Added sprites for showing animated shower and heater icons
2021-09-03 Added heater address
2021-09-03 added handlers for reading device config messages
2021-09-04 erase previous values in display if they were longer than current value
2021-09-05 Ignore platformio-device-monitor logfiles
2021-09-05 Network configuration through WiFiManager is (finally) working correctly
    [main.cpp]
2021-09-06 measured flow and confirmed it is indeed liters per minute
2021-09-06 added additional queue in between ISR and Ebus to prevent issues where ISR accesses code that is not in IRAM/DRAM
    [main.cpp]
2021-09-06 Change order of startup sequence and add some short delays, this seems to fix the reboot issues
    [main.cpp]
2021-09-06 Figured out the power budget
2021-09-11 fix bug in logger where response CRC was shown for request
    [main.cpp]
2021-09-14 Added minimal temperature logger
2021-09-14 Send temperature over ESP-NOW, hardcoded MAC for now
2021-09-15 Fix bug in logging
    [main.cpp]
2021-09-16 Replace (almost) all with
    [main.cpp, zebus-config.h, zebus-display.cpp]
2021-09-17 Log failed eBUS telegrams
    [main.cpp]
2021-09-18 Get basic voltage measurement from outdoor sensor
2021-09-18 reverted settings for TFT display back to platformio.ini since they did not work as normal defines
    [zebus-config.h, zebus-display.cpp]
2021-09-19 revert to initial color list as TFT_DARKGREY was duplicated
    [zebus-display.cpp]
2021-09-20 Switch the burden of channel detection from master to slave
2021-09-22 Move device identification to config
2021-09-22 Use logging instead of printf
2021-09-22 Add function to get last HMAC error for logging
    [main.cpp]
2021-09-23 Set sensor interval from master
2021-09-24 Correctly display eBUS queue size
    [zebus-ebus.cpp]
2021-09-25 Switching WiFi on and off now works
2021-09-26 Correctly store and display flow
    [zebus-config.h, zebus-display.cpp]
2021-09-27 Setup eBUS UART after it is fully initialized as it effectively starts eBUS. And do so in a critical section
2021-09-30 disable CPU Freq switching as it hangs one of my ESP32's
2021-09-30 Ad workaround (kludge) for detecting DS18B20 in parasitic mode
    [main.cpp]
2021-09-30 re-organize platformio.ini for oudoor sensor so parameters can be set per board
2021-10-01 Add schematic for outdoor sensor
    [outdoor-sensor.kicad_pcb, outdoor-sensor.sch]
2021-10-01 Add 3D tools
    [outdoor-sensor_housing.scad, pcb-holder.scad]
2021-10-01 Add original flexbatter tools
    [flexbatter.scad]
2021-10-01 remove warnings
    [flexbatter.scad]
2021-10-02 Read FlowTemp and ReturnTemp, only logged to console for now
2021-10-02 add 'deepen' option for CR132 battery
    [flexbatter.scad]
2021-10-02 add first version of outdoor sensor housing
    [outdoor-sensor.stl]
2021-10-03 Swap out DS18B20 for DS18B20-PAR
    [outdoor-sensor.kicad_pcb, outdoor-sensor.sch]
2021-10-04 switch to espidf
2021-10-04 Enable some power save features, uptime is actually reduced by about 65%
2021-10-04 Switch to using sdkconfig.defaults
2021-10-07 Disable interrupts while reading temperatures
2021-10-14 Switch to OneWire library that uses critical sections for bitbanging
2021-10-18 added link to discussion over calculating power usage
2021-10-26 Retrieve the values needed for calculating current power usage
2021-10-27 First setup of PID control for temperature
2021-11-03 Log some more variables from heater
2021-11-03 Set location in sensor
2021-11-03 allow for multiple sensors
2021-11-05 3D model tweaking
    [outdoor-sensor_housing.scad, pcb-holder.scad]
2021-11-11 fix wrong registration for queue-size handler
    [zebus-display.cpp]
2021-11-11 Update sensors only once per minute
2021-11-19 switch to using state-machine for display, display now keeps working while fading
2021-11-27 fix PID input
2021-11-28 De-arduino zebus-espnow.cpp
2021-11-28 tighten includes
2021-11-28 De-arduino zebus-mqtt.cpp
